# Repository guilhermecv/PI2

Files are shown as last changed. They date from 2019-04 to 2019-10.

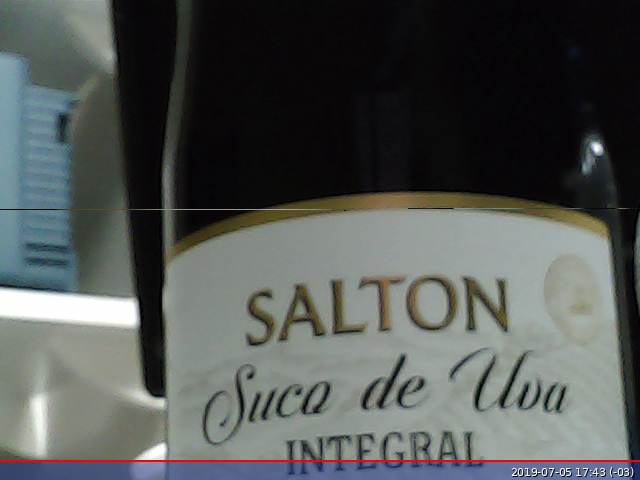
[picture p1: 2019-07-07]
Raspberry/firmware/rotulo.jpg

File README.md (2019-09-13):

# Projeto Integrador 2 - 2019/1

IFSC Engenharia Eletrônica

--> [Artigo LPAE](https://github.com/LPAE/pi2_eng_19_1/blob/master/Guilherme_Camargo_e_Jessica_Ribeiro/previa_artigo.md)

--> [Vídeo do projeto em funcionamento](https://www.youtube.com/watch?v=CO9-e8kDYCU)

Autores:

Guilherme Camargo Valese

Jéssica Ramos Ribeiro

## Hardware Utilizado

* Raspberry Pi 2B
* TCS 230
* MLX 90615
* JSN - SR04
* TCRT 5000
* LV1000 - CCD scanner
* LCD 16x2

## Instalação

O projeto utiliza a biblioteca wiringPi, incluída por  padrão nas versões do Raspbian

```bash
$ git clone https://github.com/guilhermecv/PI2.git
$ cd PI2/Raspberry/firmware
$ make
$ ./PI2
```

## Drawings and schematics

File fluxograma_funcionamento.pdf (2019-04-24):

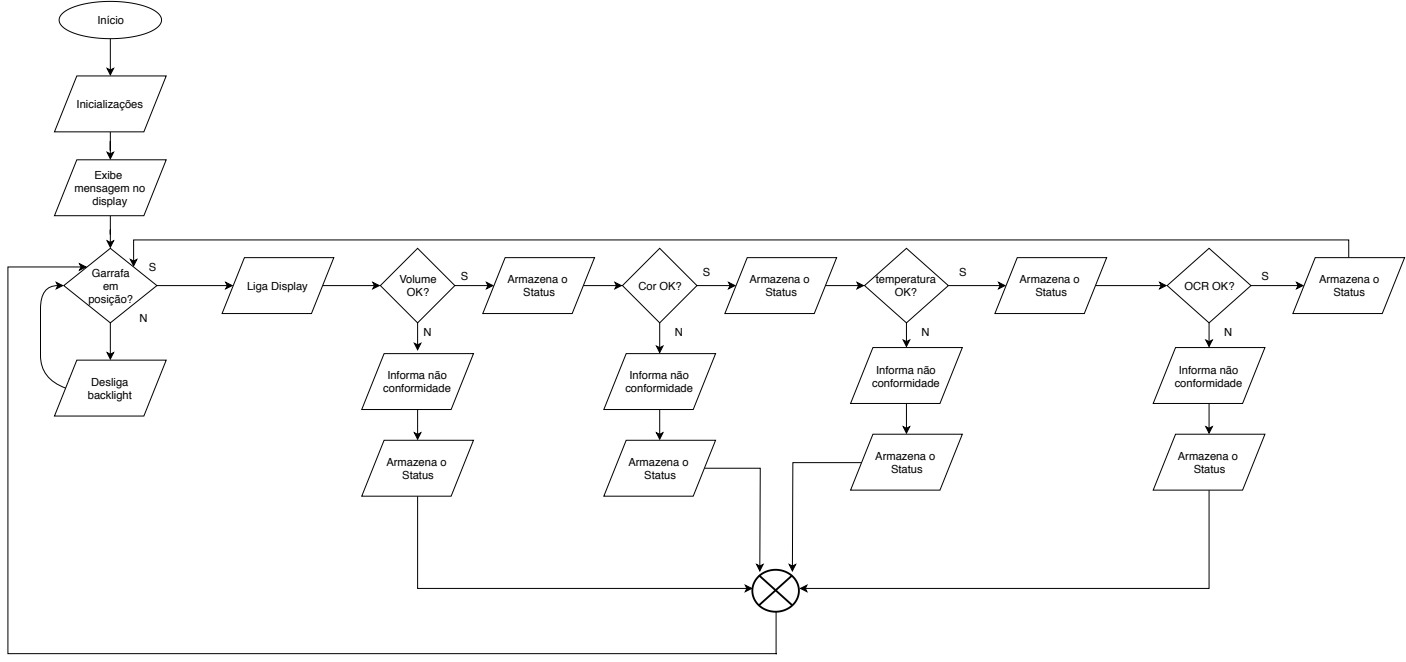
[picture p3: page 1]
Início; Inicializações; Exibe mensagem no display; Desliga backlight; Liga Display; Volume; Armazena o Status; Informa não conformidade; Garrafa em posição?; Cor OK?; Armazena o; Status; temperatura OK?; OCR OK?

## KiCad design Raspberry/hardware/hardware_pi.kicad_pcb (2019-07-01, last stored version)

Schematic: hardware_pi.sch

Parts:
BZ1: Buzzer; Buzzer_12x9.5RM7.6
C1: 100nF; C_0805_2012Metric_Pad1.29x1.40mm_HandSolder
D1: ON!; LED_0805_2012Metric_Pad1.12x1.40mm_HandSolder
D2: STATUS; LED_0805_2012Metric_Pad1.12x1.40mm_HandSolder
D3: IR_0; LED_0805_2012Metric_Pad1.12x1.40mm_HandSolder
D4: IR_1; LED_0805_2012Metric_Pad1.12x1.40mm_HandSolder
D5: IR_2; LED_0805_2012Metric_Pad1.12x1.40mm_HandSolder
D6: IR_4; LED_0805_2012Metric_Pad1.12x1.40mm_HandSolder
J101: raspberry; PinSocket_2x13_P2.54mm_Vertical
J201: LVL_HI; PinSocket_1x06_P2.54mm_Vertical
J202: LVL_LO; PinSocket_1x06_P2.54mm_Vertical
J203: DISPLAY; PinHeader_1x04_P2.54mm_Vertical
J204: TCS; PinHeader_1x05_P2.54mm_Vertical
J205: MLX; PinHeader_1x04_P2.54mm_Vertical
J401, J402, J403, J404: Conn_01x04; PinHeader_1x04_P2.54mm_Vertical
R1, R2: R_US; R_0805_2012Metric_Pad1.29x1.40mm_HandSolder
R3, R4, R5, R6, R401, R402, R403, R404, R501, R502, R503, R504, R505, R506, R507, R508, R601: R_Small; R_0805_2012Metric_Pad1.29x1.40mm_HandSolder
TP101, TP102: Test_Point; TestPoint_Pad_D1.5mm
U1: LM324A; SOIC-14_3.9x8.7mm_P1.27mm

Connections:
+3V3: C1.2, J101.1, J101.17, J202.3, J205.4, J401.2, J402.2, J403.2, J404.2, R1.1, R401.1, R402.1, R403.1, R404.1, R501.2, R503.2, R505.2, R507.2, U1.4 (V+)
+5V: J101.2, J101.4, J201.3, J203.3, J204.1
/BUZZER: J101.7, R601.2
/ECHO: J101.24
/IR_0: J101.18, R3.1, U1.1
/IR_1: J101.16, R4.1, U1.7
/IR_2: J101.12, R5.1, U1.8
/IR_3: J101.10, R6.1, U1.14
/LED_STATUS: J101.11, R2.1
/SCL_3V3: J101.5, J202.2, J205.2, TP102.1
/SCL_5V: J201.2, J203.1
/SDA_3V3: J101.3, J202.1, J205.1, TP101.1
/SDA_5V: J201.1, J203.2
/TCS_OUT: J101.23, J202.6
/TCS_S2: J101.21, J204.4
/TCS_S3: J101.19, J204.3
/TRIGGER: J101.26
GND: BZ1.2, C1.1, D1.1, D2.1, D3.1, D4.1, D5.1, D6.1, J101.6, J101.9, J101.14, J101.20, J101.25, J201.4, J202.4, J203.4, J204.2, J205.3, J401.3, J402.3, J403.3, J404.3, R502.2, R504.2, R506.2, R508.2, U1.11 (V-)
unnamed: BZ1.1, R601.1
unnamed: D1.2, R1.2
unnamed: D2.2, R2.2
unnamed: D3.2, R3.2
unnamed: D4.2, R4.2
unnamed: D5.2, R5.2
unnamed: D6.2, R6.2
unnamed: J201.6, J204.5
unnamed: J401.1, U1.3 (+)
unnamed: J401.4, R401.2
unnamed: J402.1, U1.5 (+)
unnamed: J402.4, R402.2
unnamed: J403.1, U1.10 (+)
unnamed: J403.4, R403.2
unnamed: J404.1, U1.12 (+)
unnamed: J404.4, R404.2
unnamed: R501.1, R502.1, U1.2 (-)
unnamed: R503.1, R504.1, U1.6 (-)
unnamed: R505.1, R506.1, U1.9 (-)
unnamed: R507.1, R508.1, U1.13 (-)

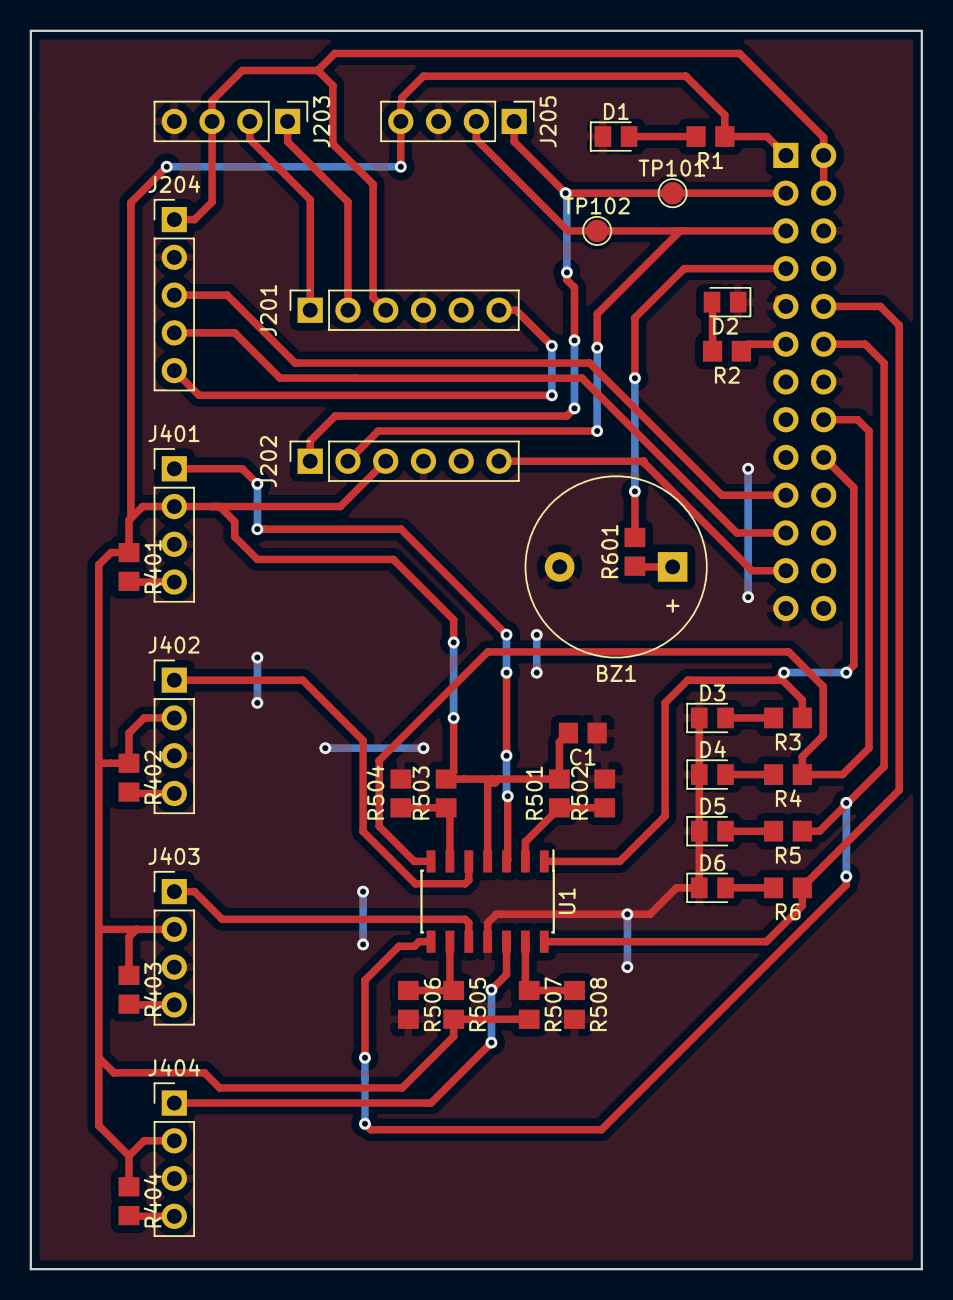
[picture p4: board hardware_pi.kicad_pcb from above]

Board: 2 copper layers, 59.9 x 83.3 mm, 40 parts (1 on the bottom side), 36 nets.

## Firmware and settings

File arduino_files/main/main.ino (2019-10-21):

/**
   @file main.c
*/

#include "main.h"

void setup() {
#ifdef USART_ON
  Serial.begin(9600);
  VERBOSE_MSG_INIT(Serial.print("Usart... OK!\n"));
#endif

#ifdef LED_ON
  LED_DDR |= (1 << LED);
  LED_PORT |= (1 << LED);
#endif

#ifdef WATCHDOG_ON
  VERBOSE_MSG_INIT(Serial.print("Watchdog..."));
  wdt_enable(WDTO_8S);
  wdt_reset();
  VERBOSE_MSG_INIT(Serial.print("OK!\n"));
#else
  VERBOSE_MSG_INIT(Serial.print("Watchdog... OFF!\n"));
#endif

#ifdef ULTRASSONIC_ON
  VERBOSE_MSG_INIT(Serial.print("Ultrassonic..."));

  VERBOSE_MSG_INIT(Serial.print("OK!\n"));
#else
  VERBOSE_MSG_INIT(Serial.print("Ultrassonic... OFF!\n"));
#endif

#ifdef WATCHDOG_ON
  wdt_reset();
#endif

#ifdef TEMPERATURE_ON
  VERBOSE_MSG_INIT(Serial.print("Temperature..."));

  VERBOSE_MSG_INIT(Serial.print("OK!\n"));
#else
  VERBOSE_MSG_INIT(Serial.print("Temperature... OFF!\n"));
#endif

#ifdef WATCHDOG_ON
  wdt_reset();
#endif

#ifdef COLOR_ON
  VERBOSE_MSG_INIT(Serial.print("Color..."));

  VERBOSE_MSG_INIT(Serial.print("OK!\n"));
#else
  VERBOSE_MSG_INIT(Serial.print("Color... OFF!\n"));
#endif

#ifdef WATCHDOG_ON
  wdt_reset();
#endif

#ifdef WATCHDOG_ON
  wdt_reset();
#endif

#ifdef DISPLAY_ON
  VERBOSE_MSG_INIT(Serial.print("Display..."));

  VERBOSE_MSG_INIT(Serial.print("OK!\n"));
#else
  VERBOSE_MSG_INIT(Serial.print("Display... OFF!\n"));
#endif

#ifdef WATCHDOG_ON
  wdt_reset();
#endif

#ifdef BARCODE_ON
  VERBOSE_MSG_INIT(Serial.print("Barcode..."));

  VERBOSE_MSG_INIT(Serial.print("OK!\n"));
#else
  VERBOSE_MSG_INIT(Serial.print("Barcode... OFF!\n"));
#endif

#ifdef WATCHDOG_ON
  wdt_reset();
#endif

#ifdef MACHINE_ON
  VERBOSE_MSG_INIT(Serial.print("Machine..."));
  machine_init();
  set_state_idle();
  VERBOSE_MSG_INIT(Serial.print("OK!\n"));
#else
  VERBOSE_MSG_INIT(Serial.print("Machine... OFF!\n"));
#endif

#ifdef WATCHDOG_ON
  wdt_reset();
#endif

}

void loop() {
#ifdef MACHINE_ON
  machine_run();
#endif

#ifdef WATCHDOG_ON
  wdt_reset();
#endif

}

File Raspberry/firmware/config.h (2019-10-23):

/**
 * Projeto Integrador 2 - 2019/1
 * Configurações gerais do projeto
 */

//====================================
//======= ATIVAÇÃO DOS MÓDULOS =======
//====================================
#define LED_ON
#define DISPLAY_ON
#define TEMPERATURE_ON
#define ULTRASSONIC_ON
#define COLOR_ON
#define OCR_ON
// #define BARCODE_ON


#define FILENAME                "log.csv"   // Nome do arquivo de log
#define DEBUG_ON						    // Habilita o envio de mensagens no console
//#define TEST_MODE						    // Habilitando este modo, as outras operações não serão executadas
#define OFFSET_DISTANCE_VALUE	  43		    // Distância medida pelo sensor com a garrafa vazia
#define DELAY					          5
#define BARCODE_TIMEOUT_VALUE	 2000
// Configurações do Buzzer
#define BUZZER_ON
//#define BUZZER_SIGNAL_ON					// Bips regulares se tudo estiver OK
#define BUZZER_IR_ON						// Bips quando algum sensor for acionado
#define BUZZER_ON_PROCESS_DELAY

//=====================================
//======== LIMITES DE VALORES =========
//=====================================
//>> VOLUME
#define MIN_VOLUME_VALUE		900
#define MAX_VOLUME_VALUE        1700
//>> TEMPERATURA
#define MAX_OBJ_TEMPERATURE     30
#define MAX_AMB_TEMPERATURE     30
//>> COR
/*
#define MAX_RED_VALUE
#define MAX_GREEN_VALUE
#define MAX_BLUE_VALUE
*/


//======== DEFINIÇÃO DOS PINOS ========
//						   wPi	Físico
#define LED_PIN				11	// 11
#define BUZZER_PIN			7	// 7

#define IR_0				1	// 18
#define IR_1				5	// 16
#define IR_2				4	// 12
#define IR_3				16	// 10

#define ECHO_PIN			6  // 24
#define TRIGGER_PIN			10  // 26

#define TCS_S2				12	// 19
#define TCS_S3				13	// 21
#define TCS_OUT				14	// 23

//====================================
//========== ENDEREÇOS I2C ===========
//====================================
#define LCD_I2CADDR			0x27
#define MLX_I2CADDR			0x5b

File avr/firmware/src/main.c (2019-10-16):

/**
 * @file main.c
 */

#include "main.h"

int main()
{
#ifdef USART_ON
  usart_init(MYUBRR, 1, 1);
  usart_send_string("PI2 - 2019/1\n\nUSART... OK!\n");
#endif /* USART_ON */

  _delay_ms(200);

#ifdef BUZZER_ON
  BUZZER_DDR |= (1 << BUZZER);
#endif

#ifdef LED_ON
  LED_DDR |= (1 << LED);
  set_led();
#endif

#ifdef MACHINE_ON
  VERBOSE_MSG_INIT(usart_send_string("Machine... "));
  machine_init();
  VERBOSE_MSG_INIT(usart_send_string("OK!\n"));
#else
  VERBOSE_MSG_INIT(usart_send_string("Machine... OFF!\n"));
#endif /* MACHINE_ON */

#ifdef ULTRASSONIC_ON
  VERBOSE_MSG_INIT(usart_send_string("Ultrassonic... "));
  ultrassonic_init();
  VERBOSE_MSG_INIT(usart_send_string("OK!\n"));
#else
  VERBOSE_MSG_INIT(usart_send_string("Ultrassonic... OFF!\n"));
#endif /* ULTRASSONIC_ON */

#ifdef TEMPERATURE_ON
  VERBOSE_MSG_INIT(usart_send_string("Temperature... "));
  mlx_init();
  VERBOSE_MSG_INIT(usart_send_string("OK!\n"));
#else
  VERBOSE_MSG_INIT(usart_send_string("Temperature... OFF!\n"));
#endif /* TEMPERATURE_ON */

#ifdef DISPLAY_ON
  VERBOSE_MSG_INIT(usart_send_string("Display... "));
  display_init();
  VERBOSE_MSG_INIT(usart_send_string("OK!\n"));
#else
  VERBOSE_MSG_INIT(usart_send_string("Display... OFF!\n"));
#endif /* DISPLAY_ON */

#ifdef COLOR_ON
  VERBOSE_MSG_INIT(usart_send_string("Color... "));
  tcs230_init();
  VERBOSE_MSG_INIT(usart_send_string("OK!\n"));
#else
  VERBOSE_MSG_INIT(usart_send_string("Color... OFF!\n"));
#endif /* COLOR_ON */

#ifdef BARCODE_ON
  VERBOSE_MSG_INIT(usart_send_string("Barcode... "));
  barcode_init();
  VERBOSE_MSG_INIT(usart_send_string("OK!\n"));
#else
  VERBOSE_MSG_INIT(usart_send_string("Barcode... OFF!\n"));
#endif /* BARCODE_ON */

  sei();

  while(1)
  {

#ifdef MACHINE_ON
    machine_run();
#else
    cpl_led();
    _delay_ms(200);

#ifdef ULTRASSONIC_ON
    usart_send_string("\nDistance: ");
    usart_send_uint16(get_distance());
    usart_send_string(" cm");
    _delay_ms(700);
#endif

#ifdef COLOR_ON

#endif

#endif /* MACHINE_ON */


#ifdef WATCHDOG_ON

#endif

  }
}

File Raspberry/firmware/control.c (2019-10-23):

/**
 * IFSC Engenharia Eletrônica
 * Projeto Integrador 2 - 2019/1
 * Controle dos processos de verificação
 * Autores: Guilherme Camargo e Jessica Ribeiro
 */

#include "control.h"

/**
 * @brief Carrega os valores para a memória
 */
void load_file()
{
	debug_msg(printf("Buscando arquivo de log...\n"));
	#ifdef DISPLAY_ON
	display_load_message();
	#endif
	FILE *flog;
	int n;
	flog = fopen(FILENAME, "r");
	if(flog == NULL)
	{
		printf("Erro ao abrir o arquivo");
		#ifdef DISPLAY_ON
		display_clear();
		display_string("   Falha na    ");
		display_set_line(LINE2);
		display_string(" Inicializacao ");
		#endif
		exit(1);
	}
	while(1)
	{
		n = fscanf(flog, "%d, %d, %d, , , , , ", &control.total, &control.passed, &control.failed);
		control.total = control.passed + control.failed;
		if(n=='\0')
			break;
	}
	fclose(flog);
}

/**
 * @brief Salva as informações do sistema
 */
void save_file()
{
	FILE *flog;
	flog=fopen(FILENAME, "w");
	fprintf(flog, "%d, %d, %d,", control.total, control.passed, control.failed);
	fprintf(flog, "%.2f, %.2f,", control.volume, control.obj_temp);
	fprintf(flog, "%d, %d, %d\n", control.red_color, control.green_color, control.blue_color);
	//fclose(flog);
	fflush(flog);
}

void set_state_idle()
{
	process_clk_div = 0;
	machine_state = IDLE,
	debug_msg(printf("\n>> Em espera\n"));
	led_div = display_div = 0;
	#ifdef DISPLAY_ON
	display_idle_message();
	#endif
}

void set_state_running()
{
	machine_state = RUNNING;
	debug_msg(printf("\n>> Iniciando verificação\n"));
	control.total++;
	#ifdef DISPLAY_ON
	display_backlight_on();
	#endif
	#ifdef LED_ON
	digitalWrite(LED_PIN, HIGH);
	#endif
}

void set_state_check_volume()
{
	process_clk_div = 0;
	machine_state = CHECK_VOLUME;
}

void set_state_check_temperature()
{
	process_clk_div = 0;
	machine_state = CHECK_TEMPERATURE;
}

void set_state_check_color()
{
	process_clk_div = 0;
	machine_state = CHECK_COLOR;
}

void set_state_check_ocr()
{
	process_clk_div = 0;
	machine_state = CHECK_OCR;
	debug_msg(printf("\n>> Iniciando leitura OCR\n"));
}

void process_failure()
{
	control.failed++;
	buzzer_process_failed();
	save_file();
	set_state_idle();
}

void process_ok()
{
	control.passed++;
	buzzer_process_passed();
	save_file();
	debug_msg(printf("Verificacao concluida com sucesso!\n"));
	set_state_idle();
}

/**
 * @brief Teste dos sensores instalados, neste modo as outras operações estão suspensas.
 */
void control_test()
{
	#ifdef ULTRASSONIC_ON
	float dist = get_distance();
	delay(10);
    calculate_volume();
	#ifdef DISPLAY_ON
	lcd_init();
	display_set_line(LINE1);
	display_string("Dist ");
	display_float(dist);
	display_string(" cm  ");
	display_set_line(LINE2);
	display_string("Vol: ");
	display_float(control.volume);
	display_string(" ml  ");
	#endif
	debug_msg(printf("\nDist: %.2f cm\nVol: %.2f ml", dist, control.volume));
	debug_msg(printf("\n"));
    delay(800);
	#endif

	#ifdef TEMPERATURE_ON
	float amb_temp = read_amb_temperature();
	delay(1);
	float obj_temp = read_obj_temperature();
	#ifdef DISPLAY_ON
	lcd_init();
	display_clear();
	display_string("Obj Temp:");
	display_float(obj_temp);
	display_set_line(LINE2);
	display_string("Amb Temp:");
	display_float(amb_temp);
	#endif
    debug_msg(printf("\nObj temp: %.2f Amb Temp: %.2f\n\n", obj_temp, amb_temp));
	delay(800);
	#endif

	#ifdef COLOR_ON
	get_color();
	#ifdef DISPLAY_ON
	display_set_line(LINE1);
	display_string("RGB Values     ");
	display_set_line(LINE2);
	display_int(control.red_color);
	display_string(" ");
	display_int(control.green_color);
	display_string(" ");
	display_int(control.blue_color);
	display_string("     ");
	#endif
    debug_msg(printf("\nR:%d G:%d B:%d\n", control.red_color, control.green_color, control.blue_color));
	debug_msg(printf("\n"));
	delay(800);
	#endif
}

void process_delay()
{
	int i;
	for(i=0;i<DELAY;i++)
	{
		delay(500);
		digitalWrite(LED_PIN, HIGH);
		delay(100);
		digitalWrite(LED_PIN, LOW);
		#ifdef BUZZER_ON_PROCESS_DELAY
		buzzer_bip();
		#endif
	}
	digitalWrite(LED_PIN, HIGH);
}

/**
 * @brief Máquina de estados para controle dos processos de verificação
 */
void control_run()
{
	switch (machine_state)
	{
		case IDLE:
			buzzer_alive();
			#ifdef LED_ON
			if(led_div++ > 300)
			{
				digitalWrite(LED_PIN, HIGH);
			}
			if(led_div++ > 600)
			{
				led_div = 0;
				digitalWrite(LED_PIN, LOW);
			}
			#endif

			#ifdef DISPLAY_ON
			if(display_div++ > 1000)
			{
				display_div = 0;
				display_backlight_off();
				display_update_status(control.total,control.passed,control.failed);
			}
			#endif

			if(!digitalRead(IR_0))
			{
				#ifdef BUZZER_IR_ON
				buzzer_ir_detected();
				#endif
				set_state_running();
				process_delay();
			}
			break;

		case RUNNING:
			#ifdef BARCODE_ON
			#ifdef DISPLAY_ON
			display_clear();
			display_string("Cod. de barras");
			#endif
			barcode_get_data();
			if(barcode_check())
			{
				#ifdef DISPLAY_ON
				display_set_line(LINE2);
				display_string("OK             ");
				#endif
				process_delay();	// Incluido para posicionar a garrafa corretamente
				set_state_check_volume();
			}
			else
			{
				#ifdef DISPLAY_ON
				display_set_line(LINE1);
				display_string("sem cadastro  ");
				#endif
				process_failure();
			}
			#else
			set_state_check_volume();
			#endif
			break;

		case CHECK_VOLUME:
			if(check_volume())
			{
				set_state_check_temperature();
			}
			else
			{
				process_failure();
			}
			break;

		case CHECK_TEMPERATURE:
			#ifdef TEMPERATURE_ON
			// if(digitalRead(IR_1))
			if(process_clk_div++ > 400)
			{
				process_clk_div = 0;
				#ifdef BUZZER_IR_ON
				buzzer_ir_detected();
				#endif
			   	process_delay();
				// Checa temperatura
				if(check_obj_temp())
				{
					set_state_check_color();
				}
				else
				{
					process_failure();
				}
			}
			#else
			set_state_check_color();
			#endif
			break;

		case CHECK_COLOR:
			#ifdef COLOR_ON
			// if(digitalRead(IR_2))
			if(process_clk_div++ > 400)
			{
				process_clk_div = 0;
				#ifdef BUZZER_IR_ON
				buzzer_ir_detected();
				#endif
				process_delay();
				// Confere os limites de cor
				if(check_color_limits())
					set_state_check_ocr();
				else
					process_failure();
			}
			#else
			set_state_check_ocr();
			#endif
			break;

		case CHECK_OCR:
			#ifdef OCR_ON
			check_ocr();
			#else
			process_ok();
			#endif
			break;


		default:
			break;
	}
}

/**
 * @brief Confere se o volume calculado está dentro dos limites
 * @return 1 Volume dentro dos limites
 * @return 0 Volume fora do permitido
 */
int check_volume()
{
	calculate_volume();
	#ifdef DISPLAY_ON
	display_volume(control.volume);
	#endif
	debug_msg(printf("\n>> Calculando volume total"));

	if(control.volume >= MIN_VOLUME_VALUE)
	{
		debug_msg(printf("\n>> OK"));
		return 1;
	}
	else
	{
		debug_msg(printf("\nValor fora do permitido!"));
		return 0;
	}
}
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

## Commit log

2019-06-26 Sensor de temperatura funcionando :)
2019-07-01 versao para teste
    [hardware_pi.kicad_pcb, hardware_pi.sch, log.csv]
2019-07-05 versao com OCR
    [log.csv]
2019-07-07 codigo de barras funcionando
    [log.csv]
2019-07-08 versao final
    [hardware_pi.kicad_pcb, hardware_pi.sch]
2019-09-13 adicionado link para vídeo do projeto
2019-10-23 alteracoes funcionamento
    [log.csv]
